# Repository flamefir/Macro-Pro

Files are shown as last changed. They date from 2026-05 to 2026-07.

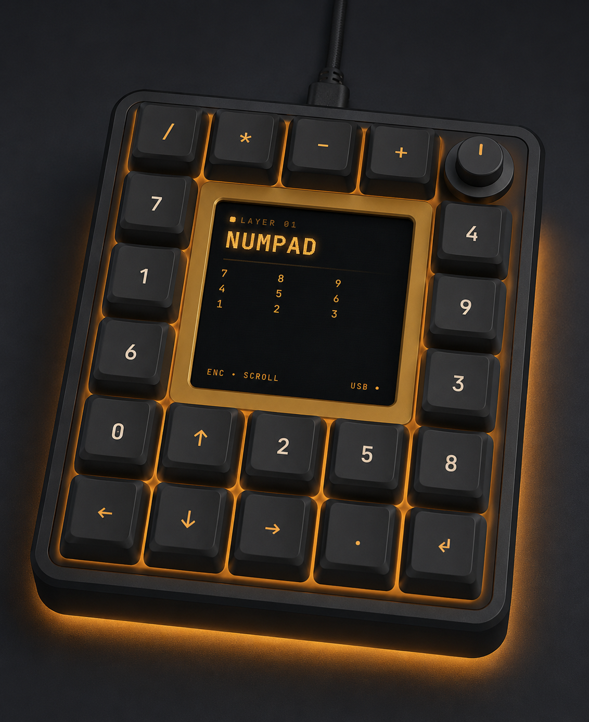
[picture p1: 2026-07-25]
information/prototype_design_build/ChatGPT Image Jun 24, 2026, 02_18_22 AM.png

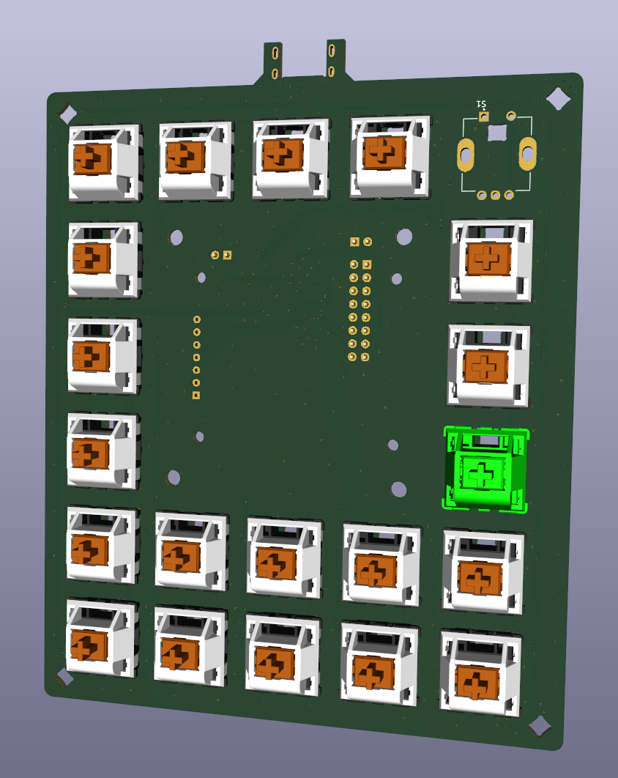
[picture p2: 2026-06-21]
information/prototype_design_build/context_pcb.png

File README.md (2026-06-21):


# Macro-Pro

## License

**Hardware** (schematics, PCB layout, enclosure/3D files): 
Licensed under [CC BY-NC-SA 4.0](https://creativecommons.org/licenses/by-nc-sa/4.0/).
You are free to build, modify, and share this design for personal and 
non-commercial use, with attribution, under the same license. 
**Commercial sale is not permitted.**

**Firmware**: Based on [QMK](https://github.com/qmk/qmk_firmware), 
licensed under the GNU GPL v2+. The firmware in this repository inherits 
that license. See the firmware directory's LICENSE for details.

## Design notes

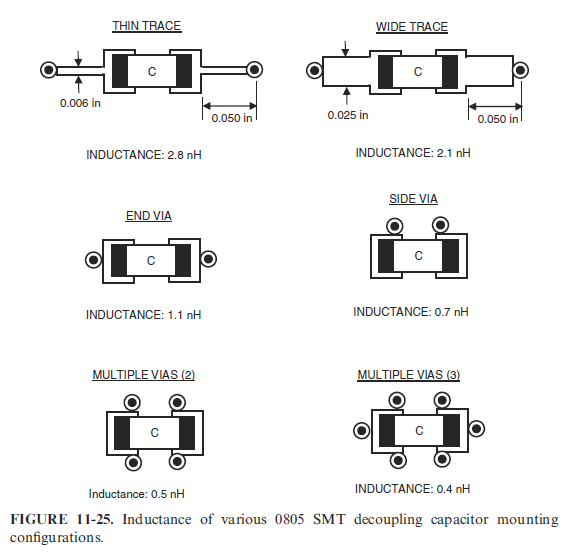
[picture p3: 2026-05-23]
hardware/Good Practice/nnIjS.png

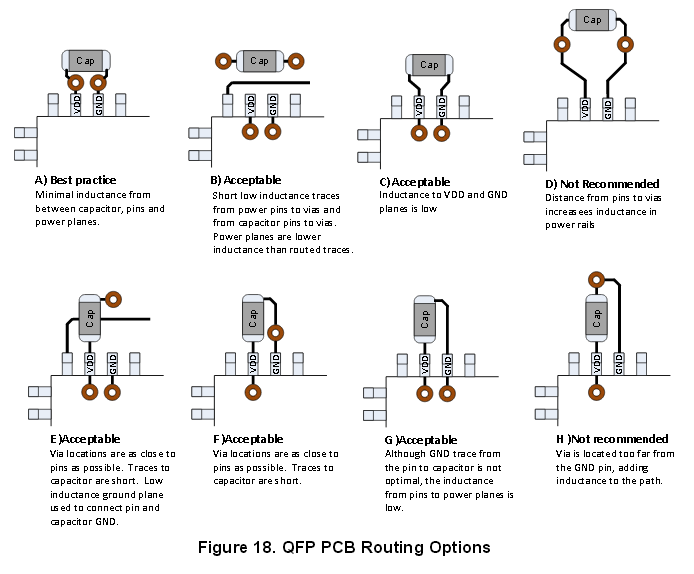
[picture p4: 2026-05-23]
hardware/Good Practice/decoupliing.png

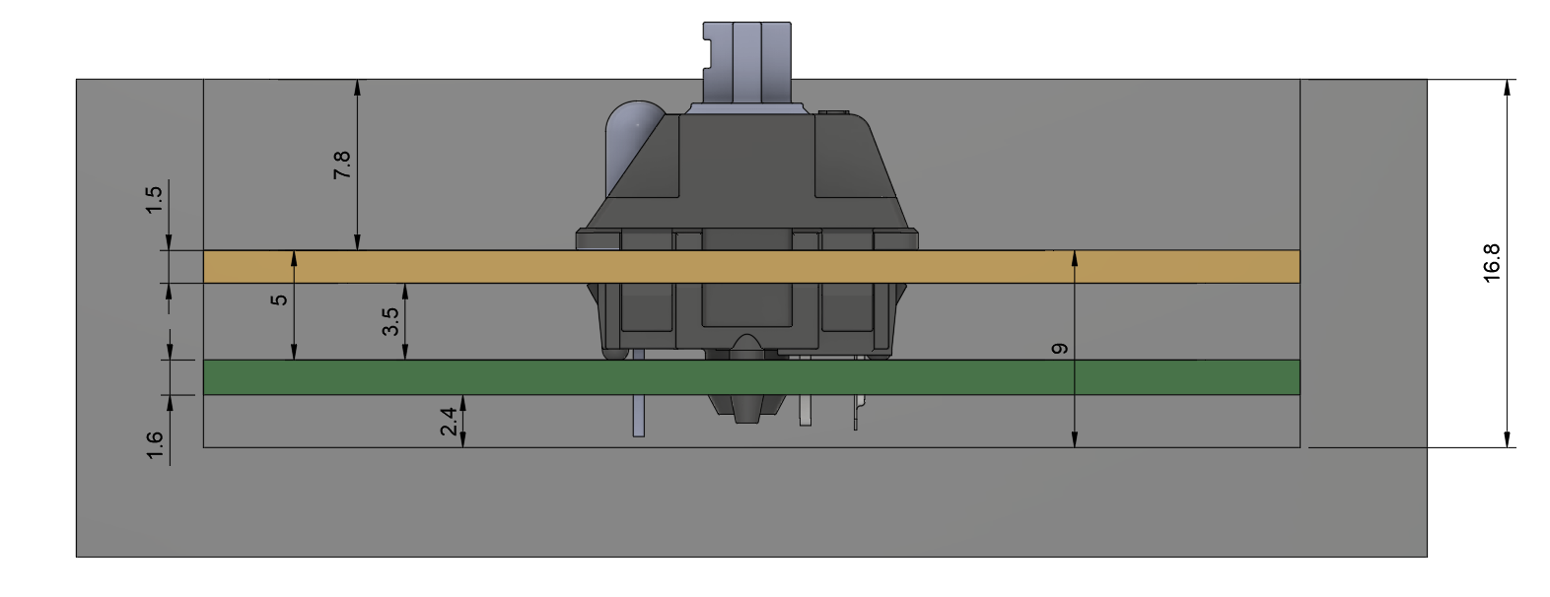
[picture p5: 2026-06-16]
information/Switch_and_plate_distances.png

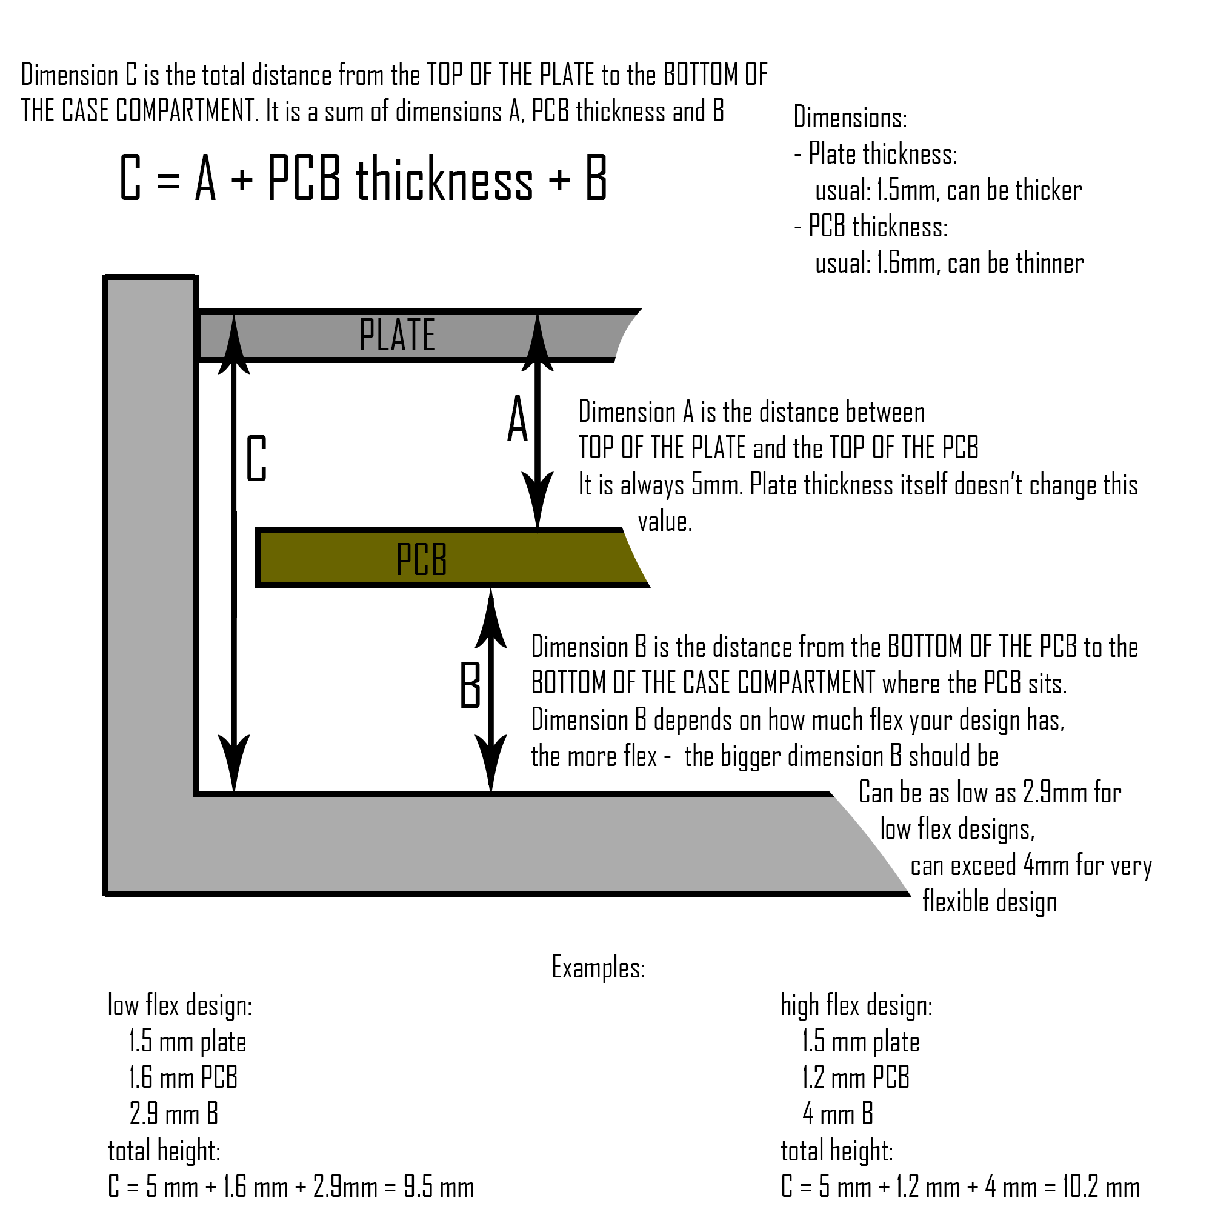
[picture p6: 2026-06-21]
information/CaseGap.png

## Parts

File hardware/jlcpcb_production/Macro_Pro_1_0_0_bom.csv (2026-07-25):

Comment | Designator | Footprint | LCSC Part #
0.1uF,"C1, C2, C3, C4, C5, CL1, CL10, CL11, CL12, CL13, CL14, CL15, CL16, CL17, CL18, CL19, CL2, CL20, CL21, CL3, CL4, CL5, CL6, CL7, CL8, CL9",01uF_0805_CAPC2012X95N,C1711
10uF,"C16, C17",10uf_0805_CAPC2012X145N,C15850
1uF,"C22, C23",0402_CAPC1005X65N_reduced_pad,C52923
0.1uF,"C25, C26, C27, C28, C29, C30, C31, C32, C44, C6",01uF_0402_CAPC1005X55N,C1525
15pF,"C33, C34",15pF_WCAP-CSGP_0805_H0.6_W,C107110
~,"D1, D10, D11, D12, D13, D14, D15, D16, D17, D18, D19, D2, D20, D21, D3, D4, D5, D6, D7, D8, D9",D_SOD-123,C917030
10k,"R1, R11, R12, R13, R14, R7, R8",10k_RESC2012X65N,C17414
1k,"R10, R6",1k_RESC2012X65N,C95781
0 | R15 | 0805 | C17477
5.1k,"R2, R3",5K1_RESC2012X65N,C27834
27,"R4, R9",27R_RESC2012X65N,C17594
470 ohm | R5 | 0603 | C23179
SW_Push_B | SW1 | SW_SPST_TL3342 | C318884
SW_Push_R | SW2 | SW_SPST_TL3342 | C318884
RP2040 | U1 | QFN-56-1EP_7x7mm_P0.4mm_EP3.2x3.2mm | C2040
AP2112K-3.3 | U3 | SOT-23-5 | C51118
USBLC6-2SC6 | U4 | SOT-23-6 | C7519
W25Q128JVS | U6 | SOIC-8_5.3x5.3mm_P1.27mm | C97521
~ | U7 | SOT95P280X145-5N | C7484
ABM8-272-T3 | Y1 | XTAL_ABM8-272-T3 | C20625731

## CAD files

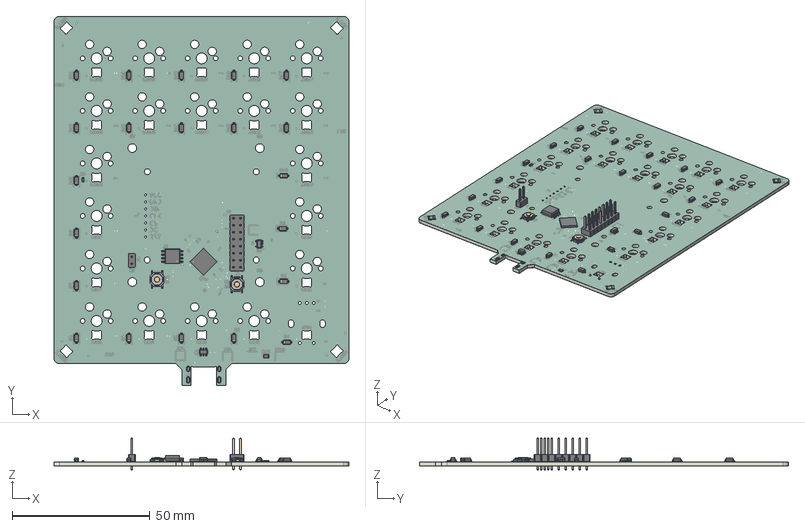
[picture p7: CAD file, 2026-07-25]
hardware/brother.step
107.0 x 134.0 x 11.5 mm
D_SOD-123 x 21
R_0603_1608Metric
SOT-23-5
SOT-23-6
PinHeader_2x08_P254mm_Vertical
SW_SPST_TL3342 x 2
PinHeader_2x01_P254mm_Vertical
QFN-56-1EP_7x7mm_P0.4mm_EP3.2x3.2mm
R_0805_2012Metric
SOIC-8_5.3x5.3mm_P1.27mm
Macro Pad Pro_silkscreen x 2
Macro Pad Pro_soldermask x 2
Macro Pad Pro_PCB

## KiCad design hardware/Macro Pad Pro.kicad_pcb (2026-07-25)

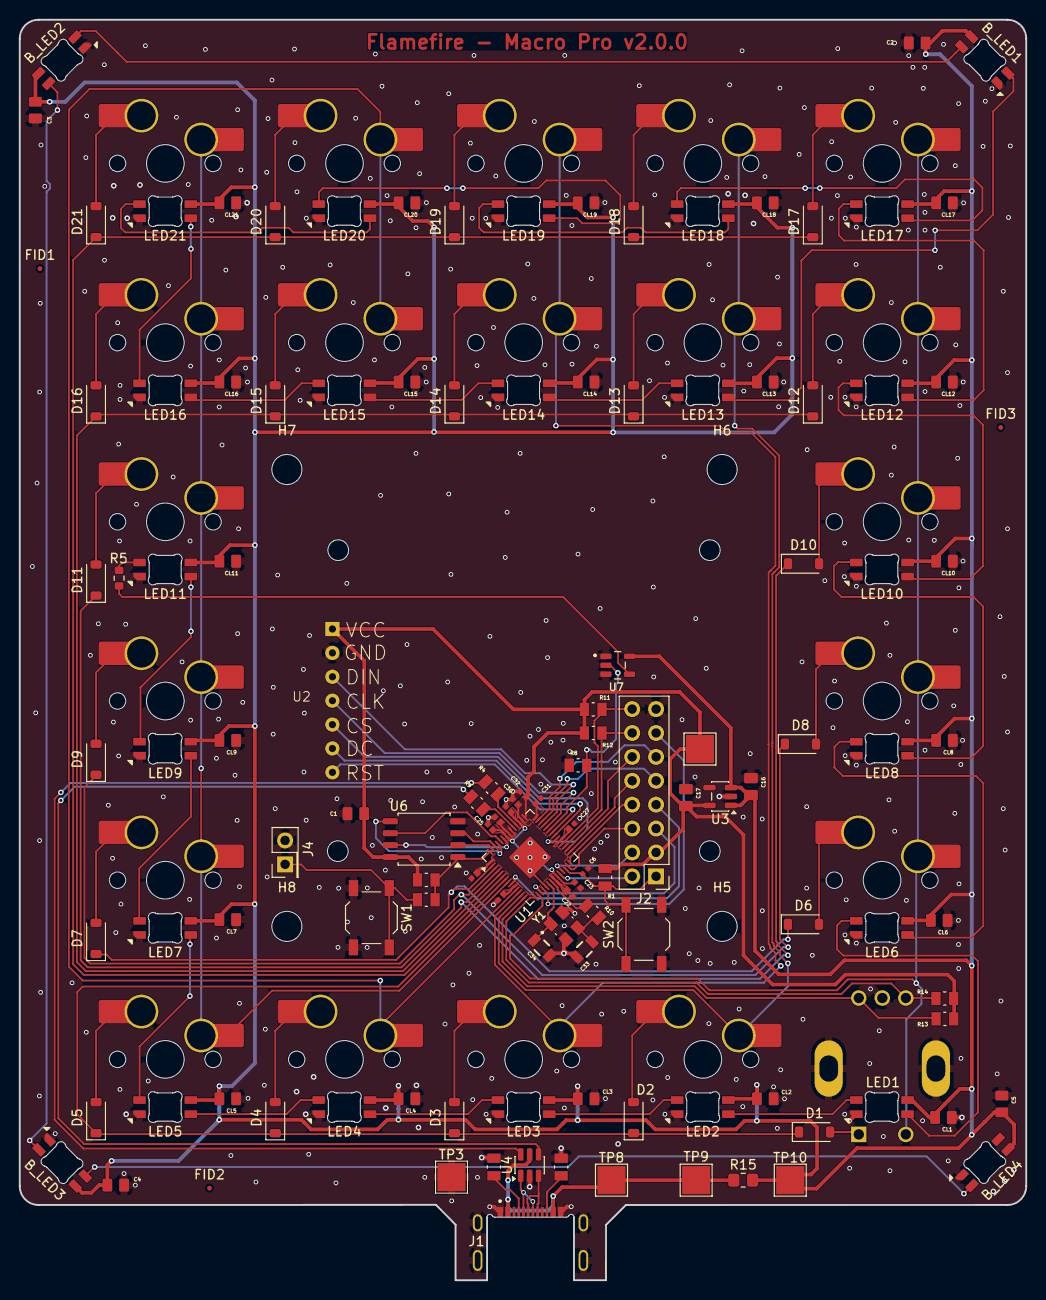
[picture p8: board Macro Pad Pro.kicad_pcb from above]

Board: 2 copper layers, 107.0 x 134.0 mm, 148 parts (1 on the bottom side), 103 nets.

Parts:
B_LED1, B_LED2, B_LED3, B_LED4: MX_SK6812MINI-E; LED_MX_6028R_Flipped
C1, C2, C3, C4, C5: 0.1uF; 01uF_0805_CAPC2012X95N
C6, C25, C26, C27, C28, C29, C30, C31, C32, C44: 0.1uF; 01uF_0402_CAPC1005X55N
C16, C17: 10uF; 10uf_0805_CAPC2012X145N
C22, C23: 1uF; 0402_CAPC1005X65N_reduced_pad
C33, C34: 15pF; 15pF_WCAP-CSGP_0805_H0.6_W
CL1, CL2, CL3, CL4, CL5, CL6, CL7, CL8, CL9, CL10, CL11, CL12, CL13, CL14, CL15, CL16, CL17, CL18, CL19, CL20, CL21: 0.1uF; 01uF_0805_CAPC2012X95N
D1, D2, D3, D4, D5, D6, D7, D8, D9, D10, D11, D12, D13, D14, D15, D16, D17, D18, D19, D20, D21: D_SOD-123
FID1, FID2, FID3: Fiducial; Fiducial_0.5mm_Mask1mm
H5, H6, H7, H8: MountingHole; MountingHole_3.2mm_M3
J1: USB_C; USB-C_MOLEX_2169900003
J2: Conn_02x08_Odd_Even; PinHeader_2x08_P2.54mm_Vertical
J4: Conn_02x01; PinHeader_2x01_P2.54mm_Vertical
LED1, LED2, LED3, LED4, LED5, LED6, LED7, LED8, LED9, LED10, LED11, LED12, LED13, LED14, LED15, LED16, LED17, LED18, LED19, LED20, LED21: MX_SK6812MINI-E; LED_MX_6028R
R1, R7, R8, R11, R12, R13, R14: 10k; 10k_RESC2012X65N
R2, R3: 5.1k; 5K1_RESC2012X65N
R4, R9: 27; 27R_RESC2012X65N
R5: 470 ohm; R_0603_1608Metric
R6, R10: 1k; 1k_RESC2012X65N
R15: 0; R_0805_2012Metric_Pad1.20x1.40mm_HandSolder
S1: RotaryEncoder; XDCR_PEC11R-4230F-S0024
S2, S3, S4, S5, S6, S7, S8, S9, S10, S11, S12, S13, S14, S15, S16, S17, S18, S19, S20, S21: MX_Hotswap_1.00u
SW1: SW_Push_B; SW_SPST_TL3342
SW2: SW_Push_R; SW_SPST_TL3342
TP2, TP3, TP8, TP9, TP10: TestPoint; TestPoint_Pad_3.0x3.0mm
U1: RP2040; QFN-56-1EP_7x7mm_P0.4mm_EP3.2x3.2mm
U2: OLED; OLED_SPI_128x128
U3: AP2112K-3.3; SOT-23-5
U4: USBLC6-2SC6; SOT-23-6
U6: W25Q128JVS; SOIC-8_5.3x5.3mm_P1.27mm
U7: SOT95P280X145-5N
Y1: ABM8-272-T3; XTAL_ABM8-272-T3

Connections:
1V1: C23.2, C25.2, C26.2, U1.23 (DVDD), U1.45 (VREG_VOUT), U1.50 (DVDD)
+3.3V: C1.2, C17.2, C22.2, C27.2, C28.2, C29.2, C30.2, C31.2, C32.2, C44.2, J2.3, R1.2, R7.2, R11.2, R12.2, R13.2, R14.2, TP2.1 (1_1), U1.1 (IOVDD), U1.10 (IOVDD), U1.22 (IOVDD), U1.33 (IOVDD), U1.42 (IOVDD), U1.43 (ADC_AVDD), U1.44 (VREG_VIN), U1.48 (USB_VDD), U1.49 (IOVDD), U2.1 (VCC), U3.5 (VOUT), U6.8 (VCC)
+5V: B_LED1.1 (VDD), B_LED2.1 (VDD), B_LED3.1 (VDD), B_LED4.1 (VDD), C2.2, C3.2, C4.2, C5.2, C16.2, CL1.2, CL2.2, CL3.2, CL4.2, CL5.2, CL6.2, CL7.2, CL8.2, CL9.2, CL10.2, CL11.2, CL12.2, CL13.2, CL14.2, CL15.2, CL16.2, CL17.2, CL18.2, CL19.2, CL20.2, CL21.2, LED1.1 (VDD), LED2.1 (VDD), LED3.1 (VDD), LED4.1 (VDD), LED5.1 (VDD), LED6.1 (VDD), LED7.1 (VDD), LED8.1 (VDD), LED9.1 (VDD), LED10.1 (VDD), LED11.1 (VDD), LED12.1 (VDD), LED13.1 (VDD), LED14.1 (VDD), LED15.1 (VDD), LED16.1 (VDD), LED17.1 (VDD), LED18.1 (VDD), LED19.1 (VDD), LED20.1 (VDD), LED21.1 (VDD), R15.2, TP10.1 (1_1), U3.1 (VIN), U3.3 (EN), U7.5 (VCC)
BOOTSEL: J4.1, R6.2, SW1.1
BS_LEDS: B_LED1.3 (DIN), LED13.2 (DOUT)
Col 0: S1.2, S6.1, S8.1, S10.1, S12.1, S17.1, U1.16 (GPIO13)
Col 1: S2.1, S13.1, S18.1, U1.13 (GPIO10)
Col 2: S3.1, S14.1, S19.1, U1.12 (GPIO9)
Col 3: S4.1, S15.1, S20.1, U1.11 (GPIO8)
Col 4: S5.1, S7.1, S9.1, S11.1, S16.1, S21.1, U1.8 (GPIO6)
ESD_DM: R4.2, U4.6
ESD_DP: R9.2, U4.4
GND: B_LED1.4 (VSS), B_LED2.4 (VSS), B_LED3.4 (VSS), B_LED4.4 (VSS), C1.1, C2.1, C3.1, C4.1, C5.1, C6.1, C16.1, C17.1, C22.1, C23.1, C25.1, C26.1, C27.1, C28.1, C29.1, C30.1, C31.1, C32.1, C33.1, C34.1, C44.1, CL1.1, CL2.1, CL3.1, CL4.1, CL5.1, CL6.1, CL7.1, CL8.1, CL9.1, CL10.1, CL11.1, CL12.1, CL13.1, CL14.1, CL15.1, CL16.1, CL17.1, CL18.1, CL19.1, CL20.1, CL21.1, J1.A1_B12 (GND), J1.B1_A12 (GND), J1.S1 (SHIELD), J1.S2 (SHIELD), J1.S3 (SHIELD), J1.S4 (SHIELD), J2.15, J4.2, LED1.4 (VSS), LED2.4 (VSS), LED3.4 (VSS), LED4.4 (VSS), LED5.4 (VSS), LED6.4 (VSS), LED7.4 (VSS), LED8.4 (VSS), LED9.4 (VSS), LED10.4 (VSS), LED11.4 (VSS), LED12.4 (VSS), LED13.4 (VSS), LED14.4 (VSS), LED15.4 (VSS), LED16.4 (VSS), LED17.4 (VSS), LED18.4 (VSS), LED19.4 (VSS), LED20.4 (VSS), LED21.4 (VSS), R2.1, R3.1, R8.1, S1.C (COM), S1.SH1 (SHIELD), S1.SH2 (SHIELD), SW1.2, SW2.2, TP3.1 (1_1), U1.19 (TESTEN), U1.57 (GND), U2.2 (GND), U3.2 (GND), U4.2, U6.4 (GND), U7.1 (~OE), U7.3 (GND), Y1.2 (GND), Y1.4 (GND)
LEDS: R8.2, U1.37 (GPIO25), U7.2 (A)
LEDS_DIN: R5.1, U7.4 (Y)
MCU_DM: R4.1, U1.46 (USB_DM)
MCU_DP: R9.1, U1.47 (USB_DP)
NRST: C6.2, J2.1, R1.1, SW2.1, U1.26 (RUN)
unnamed: B_LED1.2 (DOUT), B_LED2.3 (DIN)
unnamed: B_LED2.2 (DOUT), B_LED3.3 (DIN)
unnamed: B_LED3.2 (DOUT), B_LED4.3 (DIN)
unnamed: C33.2, R10.1, Y1.3
unnamed: D1.2 (A), S1.1
unnamed: D2.2 (A), S2.2
unnamed: D3.2 (A), S3.2
unnamed: D4.2 (A), S4.2
unnamed: D5.2 (A), S5.2
unnamed: D6.2 (A), S6.2
unnamed: D7.2 (A), S7.2
unnamed: D8.2 (A), S8.2
unnamed: D9.2 (A), S9.2
unnamed: D10.2 (A), S10.2
unnamed: D11.2 (A), S11.2
unnamed: D12.2 (A), S12.2
unnamed: D13.2 (A), S13.2
unnamed: D14.2 (A), S14.2
unnamed: D15.2 (A), S15.2
unnamed: D16.2 (A), S16.2
unnamed: D17.2 (A), S17.2
unnamed: D18.2 (A), S18.2
unnamed: D19.2 (A), S19.2
unnamed: D20.2 (A), S20.2
unnamed: D21.2 (A), S21.2
unnamed: J1.A5 (CC1), R2.2
unnamed: J1.B5 (CC2), R3.2
unnamed: LED1.3 (DIN), LED2.2 (DOUT)
unnamed: LED1.2 (DOUT), LED6.3 (DIN)
unnamed: LED2.3 (DIN), LED3.2 (DOUT)
unnamed: LED3.3 (DIN), LED4.2 (DOUT)
unnamed: LED4.3 (DIN), LED5.2 (DOUT)
unnamed: LED5.3 (DIN), LED7.2 (DOUT)
unnamed: LED6.2 (DOUT), LED8.3 (DIN)
unnamed: LED7.3 (DIN), LED9.2 (DOUT)
unnamed: LED8.2 (DOUT), LED10.3 (DIN)
unnamed: LED10.2 (DOUT), LED12.3 (DIN)
unnamed: LED11.3 (DIN), R5.2
unnamed: LED9.3 (DIN), LED11.2 (DOUT)
unnamed: LED12.2 (DOUT), LED17.3 (DIN)
unnamed: LED13.3 (DIN), LED14.2 (DOUT)
unnamed: LED14.3 (DIN), LED15.2 (DOUT)
unnamed: LED15.3 (DIN), LED16.2 (DOUT)
unnamed: LED16.3 (DIN), LED21.2 (DOUT)
unnamed: LED17.2 (DOUT), LED18.3 (DIN)
unnamed: LED18.2 (DOUT), LED19.3 (DIN)
unnamed: LED19.2 (DOUT), LED20.3 (DIN)
unnamed: LED20.2 (DOUT), LED21.3 (DIN)
OLED_CLK: U1.38 (GPIO26/ADC0), U2.4 (CLK)
OLED_CS: U1.34 (GPIO22), U2.5 (CS)
OLED_DC: U1.35 (GPIO23), U2.6 (DC)
OLED_MOSI: U1.39 (GPIO27/ADC1), U2.3 (MOSI/DIN)
OLED_RST: U1.36 (GPIO24), U2.7 (RST)
QSPI_SCLK: U1.52 (QSPI_SCLK), U6.6 (CLK)
QSPI_SD1: U1.55 (QSPI_SD1), U6.2 (DO/IO_{1})
QSPI_SD2: U1.54 (QSPI_SD2), U6.3 (~WP/IO_{2})
QSPI_SD3: U1.51 (QSPI_SD3), U6.7 (~HOLD/~RESET/IO_{3})
QSPI_SDO: U1.53 (QSPI_SD0), U6.5 (DI/IO_{0})
QSPI_SS: R6.1, R7.1, U1.56 (~QSPI_SS), U6.1 (~CS)
RCpinA: R13.1, S1.A, U1.14 (GPIO11)
RCpinB: R14.1, S1.B, U1.15 (GPIO12)
Row 0: D1.1 (K), D2.1 (K), D3.1 (K), D4.1 (K), D5.1 (K), U1.7 (GPIO5)
Row 1: D6.1 (K), D7.1 (K), U1.2 (GPIO0)
Row 2: D8.1 (K), D9.1 (K), U1.3 (GPIO1)
Row 3: D10.1 (K), D11.1 (K), U1.4 (GPIO2)
Row 4: D12.1 (K), D13.1 (K), D14.1 (K), D15.1 (K), D16.1 (K), U1.5 (GPIO3)
Row 5: D17.1 (K), D18.1 (K), D19.1 (K), D20.1 (K), D21.1 (K), U1.6 (GPIO4)
SCL: J2.16, R11.1, U1.32 (GPIO21)
SDA: J2.14, R12.1, U1.31 (GPIO20)
UMP_13: J2.5, U1.17 (GPIO14)
UMP_14: J2.9, U1.40 (GPIO28/ADC2)
UMP_15: J2.7, U1.9 (GPIO7)
UMP_16: J2.6, U1.27 (GPIO16)
UMP_17: J2.10, U1.29 (GPIO18)
UMP_18: J2.12, U1.30 (GPIO19)
UMP_19: J2.8, U1.28 (GPIO17)
UMP_20: J2.11, U1.41 (GPIO29/ADC3)
UMP_21: J2.13, U1.18 (GPIO15)
UMP_SWCLK: J2.2, U1.24 (SWCLK)
UMP_SWDIO: J2.4, U1.25 (SWDIO)
USB_C_DM: J1.A7 (DN1), J1.B7 (DN2), U4.1
USB_C_DP: J1.A6 (DP1), J1.B6 (DP2), U4.3
VBUS: J1.A4_B9 (VBUS), J1.B4_A9 (VBUS), R15.1, TP8.1 (1_1), TP9.1 (1_1), U4.5
XIN: C34.2, U1.20 (XIN), Y1.1
XOUT: R10.2, U1.21 (XOUT)

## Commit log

2026-02-25 First upload of project
    [Macro Pad Pro.kicad_pcb, Macro Pad Pro.kicad_sch, Macro_Base.SLDPRT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]
2026-05-23 Finished PCB, TODO finish the DRC warnings n stuff and send to review
    [Macro Pad Pro.kicad_pcb, Macro Pad Pro.kicad_sch, Macro_Base.SLDPRT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]
2026-06-01 from work pc
    [Macro Pad Pro.kicad_pcb, Macro Pad Pro.kicad_sch]
2026-06-15 Changes ready for review
    [Macro Pad Pro.kicad_sch]
2026-06-15 Updated the datalines routing, to be more simple, but longer
    [Macro Pad Pro.kicad_pcb]
2026-06-16 added some design files for making a plate
    [Macro Pad Pro.kicad_pcb]
2026-06-21 cleaned up BOM and updated most components with LCSC number and MPN, sent to PCBWay for review
    [Macro Pad Pro.kicad_pcb, Macro Pad Pro.kicad_pcb_bom.csv, Macro Pad Pro.kicad_pcb_positions.csv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]
2026-06-21 Added license files
    [Macro Pad Pro.kicad_pcb, Macro Pad Pro.kicad_pcb_bom.csv, Macro Pad Pro.kicad_pcb_positions.csv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]
2026-06-23 Fixed ERC component footprint
    [Macro Pad Pro.kicad_pcb, Macro Pad Pro.kicad_sch]
2026-06-25 Remove enclosure — moved to Macro-Pro-Enclosure repo
    [Macro_Base.SLDPRT, Macro_Base.STL, Macro_Bottom.SLDPRT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]
2026-07-25 Update PCB design; add production and prototype files
    - Update KiCad PCB and schematic (ERC/footprint fixes)
    - Regenerate v1.0.0 production package (BOM, positions, designators, netlist)
    - Add JLCPCB and new PCBWay production outputs
    - Add 10uF 0805 footprint to Personal.pretty and brother.step
    - Add prototype design/build photos
    - Refresh design backups; remove stale lock files and old PCBWay run
    [Macro Pad Pro.kicad_pcb, Macro Pad Pro.kicad_pcb_bom.csv, Macro Pad Pro.kicad_pcb_positions.csv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]

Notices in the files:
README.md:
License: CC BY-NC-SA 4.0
